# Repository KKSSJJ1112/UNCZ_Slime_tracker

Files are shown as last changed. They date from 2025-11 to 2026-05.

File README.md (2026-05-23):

<h2 align="center">🚧 開発中 / 개발중 / Under Development 🚧</h2>

---

# UNCZ SlimeVR Tracker

[🇯🇵 日本語](#日本語) | [🇰🇷 한국어](#한국어) | [🇺🇸 English](#english)

<p align="center">
  <!-- 実演GIF / 실연 GIF / Demo GIF -->
  Demo
</p>

---

## 日本語

### 1. 概要

UNCZ SlimeVR Tracker は SlimeVR エコシステム互換のカスタム IMU トラッカーボードである。ESP32-C3 を中心に IMU・磁気センサ・バッテリー充電・昇降圧 DC-DC を 1 枚に統合し、USB-C 1 ポートで充電とファームウェア書き込みを兼ねる構成となっている。

- ボードサイズ: **約 50mm × 35mm**
- 電源: 1 セル Li-ion / Li-Po **1100mAh**
- 通信: Wi-Fi (ESP32-C3 内蔵)
- 充電/通信: USB-C 単一ポート
- 4 層 PCB 設計

### 2. 使用 IC 一覧

| 役割 | 型番 | 主な仕様 |
|---|---|---|
| MCU | ESP32-C3-MINI-1-H4X | RISC-V, Wi-Fi/BLE, 内蔵アンテナ |
| 昇降圧 DC-DC | TPS63802DSGR | Iq 11µA, EN ピン制御 |
| 充電 IC | BQ24232HRGTR | パワーパス内蔵, OVP 28V |
| IMU | LSM6DSV16XTR | 6 軸, I²C 0x6B |
| 磁気センサ | QMC6309 | 3 軸, I²C 0x7C (オプション実装) |
| USB データ TVS | USBLC6-2SC6 | D+/D- ESD 保護 |
| バッテリー | 1100mAh 1S Li-ion/Li-Po | 公称 3.7V |

### 3. 出力 CLC フィルタ

TPS63802 の出力リップル抑制のため、共振周波数 **約 1.4MHz** をターゲットとした CLC フィルタを実装している。

**フィルタ構成**
- C1 (前段): **10µF**
- L: **1µH**
- C2 (後段): **10µF**
- 共振周波数: f₀ = 1 / (2π√(LC)) ≈ 1.59MHz (C 並列換算)

**スナバ・ダンピング**
LC 共振による Q 値スパイクを抑えるため、後段に並列スナバを配置。
- ダンピング抵抗: **1Ω 抵抗 × 3 個並列 = 0.33Ω**
- スナバ容量: **22µF × 3 個並列 = 66µF**

この構成によりフィルタの Q 値を適切に下げ、過渡応答時のリンギングを抑制している。

<p align="center">
  <!-- LTspice シミュレーション画像 -->
  LTspice Simulation
</p>

### 4. ファイル構成

| フォルダ | 内容 |
|---|---|
| `pic/` | 測定写真、実演 GIF |
| `EASY_EDA_PRO/` | EasyEDA Pro プロジェクトファイル、ライブラリファイル |
| `JLC_PCB/` | ガーバーファイル、BOM、Pick & Place ファイル |
| `Datasheet/` | 使用部品のデータシート |
| `Firmware/` | SlimeVR オープンソースベースのファームウェア |
| `License/` | ライセンスファイル |

### 5. ファームウェア

本プロジェクトのファームウェアに関するすべての部分は **[SlimeVR オープンソースプロジェクト](https://github.com/SlimeVR/SlimeVR-Tracker-ESP)** に準拠する。

### 6. リビジョン履歴

| Rev | 内容 |
|-----|---|
| REV1 | モジュールベースの拡張ボード設計 |
| REV5 | チップベースの再設計 (現行) |

### 7. ライセンス

- **ハードウェア (PCB, 回路図, 3D ファイル)**: [MIT License](https://github.com/KKSSJJ1112/UNCZ_Slime_tracker/blob/main/License/MIT)
- **ドキュメント**: [CC BY-SA 4.0](https://creativecommons.org/licenses/by-sa/4.0/)

---

## 한국어

### 1. 개요

UNCZ SlimeVR Tracker는 SlimeVR 생태계와 호환되는 커스텀 IMU 트래커 보드입니다. ESP32-C3를 중심으로 IMU, 자력계, 배터리 충전 회로, 벅부스트 DC-DC를 한 장의 PCB에 통합했으며, 단일 USB-C 포트로 충전과 펌웨어 장입을 모두 처리합니다.

- 보드 사이즈: **약 50mm × 35mm**
- 전원: 1셀 Li-ion / Li-Po **1100mAh**
- 통신: Wi-Fi (ESP32-C3 내장)
- 충전/통신: USB-C 단일 포트
- 4레이어 PCB 설계

### 2. 사용 IC 목록

| 역할 | 부품 | 주요 사양 |
|---|---|---|
| MCU | ESP32-C3-MINI-1-H4X | RISC-V, Wi-Fi/BLE, 내장 안테나 |
| 벅부스트 DC-DC | TPS63802DSGR | Iq 11µA, EN 핀 제어 |
| 충전 IC | BQ24232HRGTR | 파워패스 내장, OVP 28V |
| IMU | LSM6DSV16XTR | 6축, I²C 0x6B |
| 자력계 | QMC6309 | 3축, I²C 0x7C (옵션 실장) |
| USB 데이터 TVS | USBLC6-2SC6 | D+/D- ESD 보호 |
| 배터리 | 1100mAh 1S Li-ion/Li-Po | 공칭 3.7V |

### 3. 출력 CLC 필터

TPS63802 출력 리플 억제를 위해 공진 주파수 **약 1.4MHz**를 타겟으로 한 CLC 필터를 구성했습니다.

**필터 구성**
- C1 (전단): **10µF**
- L: **1µH**
- C2 (후단): **10µF**
- 공진 주파수: f₀ = 1 / (2π√(LC)) ≈ 1.59MHz (C 병렬 환산)

**스너버 댐핑**
LC 공진으로 인한 Q값 스파이크를 억제하기 위해 후단에 병렬 스너버를 배치하여 의도적으로 Q값을 조정했습니다.
- 댐핑 저항: **1Ω 저항 3개 병렬 = 0.33Ω**
- 스너버 커패시터: **22µF 3개 병렬 = 66µF**

이 구성으로 필터의 Q값을 적절히 낮춰 과도 응답 시 링잉을 억제합니다.

<p align="center">
  <!-- LTspice 시뮬레이션 이미지 -->
  LTspice Simulation
</p>

### 4. 파일 구성

| 폴더 | 내용 |
|---|---|
| `pic/` | 측정 사진, 실연 GIF |
| `EASY_EDA_PRO/` | EasyEDA Pro 프로젝트 파일, 라이브러리 파일 |
| `JLC_PCB/` | 거버 파일, BOM, Pick & Place 파일 |
| `Datasheet/` | 사용 부품 데이터시트 |
| `Firmware/` | SlimeVR 오픈소스 기반 펌웨어 |
| `License/` | 라이센스 파일 |

### 5. 펌웨어

본 프로젝트의 펌웨어와 관련된 모든 부분은 **[SlimeVR 오픈소스 프로젝트](https://github.com/SlimeVR/SlimeVR-Tracker-ESP)** 를 따릅니다.

### 6. 리비전 히스토리

| Rev | 내용 |
|-----|---|
| REV1 | 모듈 기반의 확장 보드 설계 |
| REV5 | 칩 기반의 재설계 (현행) |

### 7. 라이센스

- **하드웨어 (PCB, 회로도, 3D 파일)**: [MIT License](https://github.com/KKSSJJ1112/UNCZ_Slime_tracker/blob/main/License/MIT)
- **문서**: [CC BY-SA 4.0](https://creativecommons.org/licenses/by-sa/4.0/)

---

## English

### 1. Overview

The UNCZ SlimeVR Tracker is a custom IMU tracker board compatible with the SlimeVR ecosystem. Built around the ESP32-C3, it integrates an IMU, magnetometer, battery charger, and buck-boost DC-DC converter onto a single PCB, with a single USB-C port handling both charging and firmware upload.

- Board size: **~50mm × 35mm**
- Power: 1-cell Li-ion / Li-Po **1100mAh**
- Communication: Wi-Fi (ESP32-C3 built-in)
- Charging/Communication: Single USB-C port
- 4-layer PCB design

### 2. IC List

| Role | Part | Key Specs |
|---|---|---|
| MCU | ESP32-C3-MINI-1-H4X | RISC-V, Wi-Fi/BLE, built-in antenna |
| Buck-Boost DC-DC | TPS63802DSGR | Iq 11µA, EN pin control |
| Charger IC | BQ24232HRGTR | Power path built-in, OVP 28V |
| IMU | LSM6DSV16XTR | 6-axis, I²C 0x6B |
| Magnetometer | QMC6309 | 3-axis, I²C 0x7C (optional) |
| USB Data TVS | USBLC6-2SC6 | D+/D- ESD protection |
| Battery | 1100mAh 1S Li-ion/Li-Po | Nominal 3.7V |

### 3. Output CLC Filter

A CLC filter targeting a resonant frequency of **~1.4MHz** is implemented to suppress output ripple from the TPS63802.

**Filter Configuration**
- C1 (front): **10µF**
- L: **1µH**
- C2 (rear): **10µF**
- Resonant frequency: f₀ = 1 / (2π√(LC)) ≈ 1.59MHz (with parallel C)

**Snubber Damping**
To suppress the Q-factor spike caused by LC resonance, a parallel snubber is placed at the rear stage, intentionally tuning the Q-factor.
- Damping resistor: **1Ω × 3 in parallel = 0.33Ω**
- Snubber capacitor: **22µF × 3 in parallel = 66µF**

This configuration appropriately lowers the filter's Q-factor, suppressing ringing during transient response.

<p align="center">
  <!-- LTspice simulation image -->
  LTspice Simulation
</p>

### 4. File Structure

| Folder | Contents |
|---|---|
| `pic/` | Measurement photos, demo GIFs |
| `EASY_EDA_PRO/` | EasyEDA Pro project files, library files |
| `JLC_PCB/` | Gerber files, BOM, Pick & Place files |
| `Datasheet/` | Datasheets of used components |
| `Firmware/` | SlimeVR open-source-based firmware |
| `License/` | License files |

### 5. Firmware

All firmware-related portions of this project follow the **[SlimeVR open-source project](https://github.com/SlimeVR/SlimeVR-Tracker-ESP)**.

### 6. Revision History

| Rev | Description |
|-----|---|
| REV1 | Module-based expansion board design |
| REV5 | Chip-based redesign (current) |

### 7. License

- **Hardware (PCB, Schematics, 3D files)**: [MIT License](https://github.com/KKSSJJ1112/UNCZ_Slime_tracker/blob/main/License/MIT)
- **Documentation**: [CC BY-SA 4.0](https://creativecommons.org/licenses/by-sa/4.0/)

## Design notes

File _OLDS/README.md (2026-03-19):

asd

# UNCZ_Slime_tracker

[English](#english) | [한국어](#한국어)

---

## English

### Overview
Custom SlimeVR tracker.

### Specifications
| Item | Description |
|---|---|
| MCU | ESP32-C3 Super Mini |
| IMU | SlimeVR Mumo Breakout Module V1 (ICM-45686 + QMC6309) |
| Battery | 1100mAh Li-Po |
| PCB Size | ~80mm x 30mm |

## REV01
<details>
### Features
- **Optimized Power Circuit**: Minimized ripple and noise (77mV → 20mV)
- **Compact Form Factor**: Streamlined 2-layer PCB design
- **Production Ready**: Includes JLCPCB manufacturing files

### Repository Structure
```
├── 3D/                    # 3D model files (STL - case, mount, etc.)
├── Datasheets/            # Component datasheets
├── Demonstration_Video/   # Demo videos
├── SlimeVR/               # SlimeVR firmware source code
├── KiCad/                 # KiCad project files
│   ├── *.kicad_pcb
│   ├── *.kicad_sch
│   └── *.kicad_pro
├── License/               # License files
├── Measurement_Pic/       # Power circuit ripple measurement photos
└── Production/            # Manufacturing files
    ├── BOM.csv            # Bill of Materials (JLCPCB format)
    └── Positions.csv      # Pick and place file
```

### Manufacturing
Production files are optimized for JLCPCB:
1. Generate Gerber and drill files from KiCad project (`KiCad/` folder)
2. Upload generated Gerber files to JLCPCB
3. Use provided BOM and position files for SMT assembly

### Firmware

Based on the official SlimeVR open-source firmware.  
Original repository: https://github.com/SlimeVR/SlimeVR-Tracker-ESP

This repository contains only the modified files. Clone the original repository first, then apply these changes.

#### Modified Files

| File | Changes |
|---|---|
| `src/defines.h` | Hardcoded WiFi credentials, battery monitoring disabled, dual sensor config (`SENSOR_DESC_LIST` - 0x69, 0x68), SDO pin control (`PIN_IMU_SDO = 5`) |
| `src/main.cpp` | SDO pin initialization (GPIO5 → HIGH, 200ms delay), WiFi credentials fallback |
| `src/network/wifihandler.cpp` | Hardcoded WiFi credentials (`tryHardcodedCredentials()` function) |
| `src/network/wifihandler.h` | WiFi timeout reduced: 11s → 4s |
| `src/sensors/softfusion/drivers/icm45base.h` | Default I2C address changed: 0x68 → 0x69 |
| `board-defaults.json` | `BOARD_LOLIN_C3_MINI` dual sensor config (Sensor 0: 0x69, Sensor 1: 0x68) |
| `platformio.ini` | Upload flags adjusted (`--after=no_reset`) |

#### Key Features
- ✅ Dual sensor support (I2C address 0x68 + 0x69)
- ✅ Dynamic SDO pin control (GPIO5 for address separation)
- ✅ Improved WiFi stability (timeout adjustment, multiple fallback)
- ✅ Battery monitoring disabled

#### Dual Sensor Setup
When using 2 sensors, **short the INT pin of the secondary tracker to GND**.

#### Build & Flash
1. Install PlatformIO
2. Open `SlimeVR/` folder in VSCode
3. Build and upload to ESP32-C3

#### WiFi Configuration
Edit the following files and replace WiFi credentials:

1. **src/defines.h** (Line 13, 18)
   - Change `WIFI_CREDS_SSID` to your WiFi SSID
   - Change `WIFI_CREDS_PASSWD` to your WiFi password

2. **src/main.cpp** (Line 104, 105)
   - Change `WIFI_CREDS_SSID` to your WiFi SSID  
   - Change `WIFI_CREDS_PASSWD` to your WiFi password

3. **src/network/wifihandler.cpp** (Line 310, 311)
   - Change `HARDCODED_SSID` to your WiFi SSID
   - Change `HARDCODED_PASSWD` to your WiFi password

**Note:** All three locations must match for reliable WiFi connection.

### Power Circuit Measurement
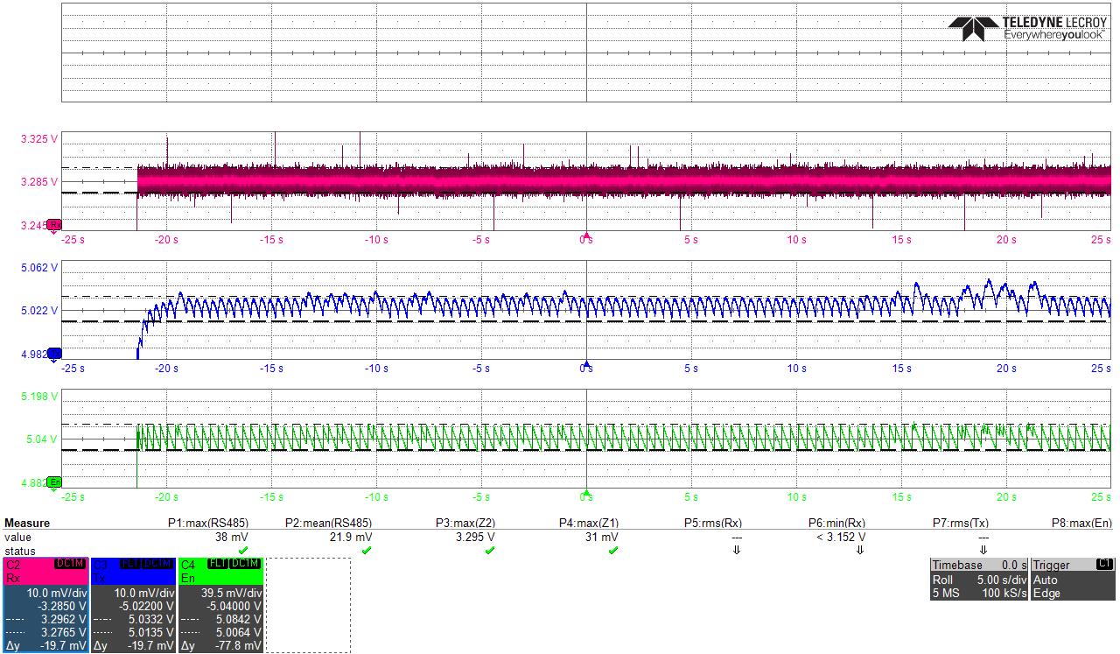
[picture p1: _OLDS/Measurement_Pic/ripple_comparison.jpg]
Power Circuit Comparison


77mV → 20mV  
From bottom to top: immediately after boost converter, after LC filter, and before final IMU power supply.
</details>

### License
- Hardware (PCB, Schematics, 3D files): [MIT License](License/MIT)
- Documentation: [CC BY-SA 4.0](https://creativecommons.org/licenses/by-sa/4.0/)

### Revision History
- **Rev03** (In Progress): Restructured power line routing and added TVS diode for ESD protection, added selectable resistor pads for I2C/SPI configuration, changed power control to EN/CE pin-based switching.
- **Rev02**: Power circuit, Charging circuit changed
- **Rev01**: Initial design

---

## 한국어

### 개요
커스텀 SlimeVR 트래커입니다.

### 사양
| 항목 | 내용 |
|---|---|
| MCU | ESP32-C3 Super Mini |
| IMU | SlimeVR Mumo Breakout Module V1 (ICM-45686 + QMC6309) |
| 배터리 | 1100mAh Li-Po |
| PCB 크기 | 약 80mm x 30mm |

## REV01
<details>
### 특징
- **전원부 최적화**: 리플 및 노이즈 최소화 (77mV → 20mV)
- **컴팩트 설계**: 2레이어 PCB 기반 간결한 설계
- **양산 대응**: JLCPCB 제조 파일 포함

### 저장소 구조
```
├── 3D/                    # 3D 모델 파일 (STL - 케이스, 마운트 등)
├── Datasheets/            # 부품 데이터시트
├── Demonstration_Video/   # 시연 영상
├── SlimeVR/               # SlimeVR 펌웨어 소스 코드
├── KiCad/                 # KiCad 프로젝트 파일
│   ├── *.kicad_pcb
│   ├── *.kicad_sch
│   └── *.kicad_pro
├── License/               # 라이선스 파일
├── Measurement_Pic/       # 전원부 리플 측정 사진
└── Production/            # 제조용 파일
    ├── BOM.csv            # 부품 목록 (JLCPCB 형식)
    └── Positions.csv      # 부품 배치 파일
```

### 제조 방법
JLCPCB 기준 제조 파일 제공:
1. KiCad 프로젝트(`KiCad/` 폴더)에서 Gerber 및 드릴 파일 생성
2. 생성된 Gerber 파일을 JLCPCB에 업로드
3. 제공된 BOM 및 위치 파일로 SMT 조립 주문

### 펌웨어

SlimeVR 공식 오픈소스 펌웨어를 기반으로 합니다.  
원본 저장소: https://github.com/SlimeVR/SlimeVR-Tracker-ESP

이 저장소에는 수정된 파일만 포함되어 있습니다. 원본 저장소를 먼저 클론한 후 변경사항을 적용하세요.

#### 수정된 파일

| 파일 | 변경 내용 |
|---|---|
| `src/defines.h` | WiFi 정보 하드코딩, 배터리 모니터링 비활성화, 듀얼 센서 설정 (`SENSOR_DESC_LIST` - 0x69, 0x68), SDO 핀 제어 (`PIN_IMU_SDO = 5`) |
| `src/main.cpp` | SDO 핀 초기화 (GPIO5 → HIGH, 200ms delay), WiFi credentials fallback |
| `src/network/wifihandler.cpp` | WiFi 정보 하드코딩 (`tryHardcodedCredentials()` 함수) |
| `src/network/wifihandler.h` | WiFi 타임아웃 단축: 11초 → 4초 |
| `src/sensors/softfusion/drivers/icm45base.h` | I2C 기본 주소 변경: 0x68 → 0x69 |
| `board-defaults.json` | `BOARD_LOLIN_C3_MINI` 듀얼 센서 설정 (Sensor 0: 0x69, Sensor 1: 0x68) |
| `platformio.ini` | 업로드 플래그 조정 (`--after=no_reset`) |

#### 핵심 기능
- ✅ 듀얼 센서 지원 (I2C 주소 0x68 + 0x69)
- ✅ SDO 핀 동적 제어 (GPIO5로 센서 주소 분리)
- ✅ WiFi 안정성 개선 (타임아웃 조정, 다중 fallback)
- ✅ 배터리 모니터링 비활성화

#### 듀얼 센서 사용 시
센서 2개 사용 시, **보조 트래커의 INT 핀을 GND에 쇼트**시켜 사용하세요.

#### 빌드 및 업로드
1. PlatformIO 설치
2. VSCode에서 `SlimeVR/` 폴더 열기
3. ESP32-C3에 빌드 및 업로드

#### WiFi 설정
아래 파일들에서 WiFi 정보를 수정하세요:

1. **src/defines.h** (13, 18번째 줄)
   - `WIFI_CREDS_SSID`를 본인의 WiFi SSID로 변경
   - `WIFI_CREDS_PASSWD`를 본인의 WiFi 비밀번호로 변경

2. **src/main.cpp** (104, 105번째 줄)
   - `WIFI_CREDS_SSID`를 본인의 WiFi SSID로 변경
   - `WIFI_CREDS_PASSWD`를 본인의 WiFi 비밀번호로 변경

3. **src/network/wifihandler.cpp** (310, 311번째 줄)
   - `HARDCODED_SSID`를 본인의 WiFi SSID로 변경
   - `HARDCODED_PASSWD`를 본인의 WiFi 비밀번호로 변경

**참고:** 세 곳 모두 동일하게 설정해야 WiFi 연결이 정상 작동합니다.

### 전원부 측정
전원부 비교

77mV → 20mV  
맨 아래부터 승압 직후, LC필터 이후, 최종 IMU 공급 직전
</details>
### 라이선스
- Hardware (PCB, Schematics, 3D files): [MIT License](License/MIT)
- Documentation: [CC BY-SA 4.0](https://creativecommons.org/licenses/by-sa/4.0/)

### 변경 이력
- **Rev03** (현재 진행중) : ESD관련한 배선 구조 변경 및 소자 추가, I2C, SPI 혼용을 위한 선택용 저항 패턴 추가, 전원제어를 EN, CE핀 기반으로 변경
- **Rev02**: 전원부, 충전부 수정
- **Rev01**: 최초 설계

---

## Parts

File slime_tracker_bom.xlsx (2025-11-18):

Reference | Qty | Value | DNP | Exclude from BOM | Exclude from Board | Footprint | JLC PART # | Datasheet
C1 | 1 | 1uF |  |  |  | Capacitor_SMD:C_0805_2012Metric | C1712 | ~
C2,C12,C13 | 3 | 10uF |  |  |  | Capacitor_SMD:C_1206_3216Metric | C70462 | ~
C3 | 1 | 22uF |  |  |  | Capacitor_SMD:C_1206_3216Metric | C5252682 | ~
C4 | 1 | 100nF |  |  |  | Capacitor_SMD:C_1206_3216Metric | C82601 | ~
C5 | 1 | 2.2uF |  |  |  | Capacitor_SMD:C_1206_3216Metric | C577211 | ~
C6 | 1 | 10uF |  |  |  | Capacitor_SMD:C_0805_2012Metric | C6119932 | ~
C7 | 1 | 0.1uF |  |  |  | Capacitor_SMD:C_0805_2012Metric | C519981 | ~
C8 | 1 | 100uF |  |  |  | Capacitor_Tantalum_SMD:CASE-B-3528-21(mm) kemet | C600583 | ~
C9,C10 | 2 | 1.5uF |  |  |  | Capacitor_SMD:C_1206_3216Metric | C282844 | ~
C11 | 1 | 1uF |  |  |  | Capacitor_SMD:C_1206_3216Metric | C107184 | ~
D1 | 1 | red |  |  |  | LED_SMD:LED_1206_3216Metric | C84270 | ~
D2 | 1 | green |  |  |  | LED_SMD:LED_1206_3216Metric | C14641 | ~
D3 | 1 | D |  |  |  | Diode_SMD:D_SOD-323 | C22624
FB1,FB2 | 2 | FerriteBead |  |  |  | Resistor_SMD:R_0805_2012Metric | C67451 | ~
H1,H2 | 2 | MountingHole | DNP | ",MountingHole:MountingHole_3.2mm_M3" | ~ | ~ | ~
H3,H5,H6 | 3 | MountingHole | DNP | MountingHole:ToolingHole_1.152mm | ~ | ~ | ~
J1 | 1 | batt | DNP | ",Connector_JST:JST_PH_S2B-PH-K_1x02_P2.00mm_Horizontal" | ~ | ~ | ~
J3 | 1 | USB_C_Receptacle_PowerOnly_6P |  |  |  | Connector_USB:USB_C_Receptacle_GCT_USB4135-GF-A_6P_TopMnt_Horizontal | C5438410 | https://www.usb.org/sites/default/files/documents/usb_type-c.zip
L1 | 1 | 6.8uH |  |  |  | slime:FXL0420 | C177241 | ~
L2 | 1 | 2.2uH |  |  |  | slime:FXL0420 | C167206 | ~
R1,R5 | 2 | 1.8MOhm |  |  |  | Resistor_SMD:R_0603_1608Metric | C13318 | ~
R2,R3,R6,R7 | 4 | 33Ohm |  |  |  | Resistor_SMD:R_0603_1608Metric | C23140 | ~
R4 | 1 | 390kOhm |  |  |  | Resistor_SMD:R_0603_1608Metric | C23150 | ~
R8 | 1 | 200kOhm |  |  |  | Resistor_SMD:R_0603_1608Metric | C25811 | ~
R9 | 1 | 1MOhm |  |  |  | Resistor_SMD:R_0603_1608Metric | C22935 | ~
R10 | 1 | 4.7kOhm |  |  |  | Resistor_SMD:R_0603_1608Metric | C23162 | ~
R11 | 1 | 3kOhm |  |  |  | Resistor_SMD:R_0603_1608Metric | C4211 | ~
R12 | 1 | 10kOhm |  |  |  | Resistor_SMD:R_0603_1608Metric | C25804 | ~
R13,R14 | 2 | 1kOhm |  |  |  | Resistor_SMD:R_0603_1608Metric | C21190 | ~
R15 | 1 | 0.4Ohm |  |  |  | Resistor_SMD:R_2010_5025Metric | C2999599 | ~
R16,R17 | 2 | 5.1kOhm |  |  |  | Resistor_SMD:R_0603_1608Metric | C23186 | ~
SW1 | 1 | SW_DPDT_x2 | DNP | Button_Switch_THT:SW_Slide_SPDT_Angled_CK_OS102011MA1Q" | ~ | ~ | ~
TP1 | 1 | SCL |  |  |  | TestPoint:TestPoint_Pad_2.5x2.5mm | ~ | ~
TP2 | 1 | SDA |  |  |  | TestPoint:TestPoint_Pad_2.5x2.5mm | ~ | ~
TP3 | 1 | 3.3v |  |  |  | TestPoint:TestPoint_Pad_2.5x2.5mm | ~ | ~
TP4 | 1 | GND |  |  |  | TestPoint:TestPoint_Pad_2.5x2.5mm | ~ | ~
TP5 | 1 | INT2 |  |  |  | TestPoint:TestPoint_Pad_2.5x2.5mm | ~ | ~
U1 | 1 | TP4056 |  |  |  | slime:TP4056_ESOP8 | C725790
U2 | 1 | ~ | DNP | "slime:Slime_IMU_mumo" | ~ | ~ | ~
U3 | 1 | TPS7A0333PDBVR |  |  |  | Package_TO_SOT_SMD:SOT-23-5 | C3749797
U4 | 1 | ESP32 SUPER MINI C3 | DNP | ",slime:esp32" | ~ | ~ | ~
U5 | 1 | TPS61090 |  |  |  | Package_DFN_QFN:QFN-16-1EP_4x4mm_P0.65mm_EP2.7x2.7mm_PullBack_ThermalVias | C206167

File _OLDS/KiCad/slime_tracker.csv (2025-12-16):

Reference | Qty | Value | DNP | Exclude from BOM | Exclude from Board | Footprint | Datasheet
C1 | 1 | 1uF |  |  |  | Capacitor_SMD:C_0805_2012Metric | ~
C2,C12,C13 | 3 | 10uF |  |  |  | Capacitor_SMD:C_1206_3216Metric | ~
C3 | 1 | 22uF |  |  |  | Capacitor_SMD:C_1206_3216Metric | ~
C4 | 1 | 100nF |  |  |  | Capacitor_SMD:C_1206_3216Metric | ~
C5 | 1 | 2.2uF |  |  |  | Capacitor_SMD:C_1206_3216Metric | ~
C6 | 1 | 10uF |  |  |  | Capacitor_SMD:C_0805_2012Metric | ~
C7 | 1 | 0.1uF |  |  |  | Capacitor_SMD:C_0805_2012Metric | ~
C8 | 1 | 100uF |  |  |  | Capacitor_Tantalum_SMD:CP_EIA-3528-21_Kemet-B | ~
C9,C10 | 2 | 1.5uF |  |  |  | Capacitor_SMD:C_1206_3216Metric | ~
C11 | 1 | 1uF |  |  |  | Capacitor_SMD:C_1206_3216Metric | ~
D1 | 1 | red |  |  |  | LED_SMD:LED_1206_3216Metric | ~
D2 | 1 | green |  |  |  | LED_SMD:LED_1206_3216Metric | ~
D3 | 1 | D |  |  |  | Diode_SMD:D_SOD-123 | ~
FB1 | 1 | FerriteBead |  |  |  | Resistor_SMD:R_0805_2012Metric | ~
H1,H2 | 2 | MountingHole |  | BOM에서 제외됨 |  | MountingHole:MountingHole_3.2mm_M3 | ~
J1 | 1 | batt |  | BOM에서 제외됨 |  | Connector_JST:JST_PH_S2B-PH-K_1x02_P2.00mm_Horizontal | ~
J3 | 1 | USB_C_Receptacle_PowerOnly_6P |  |  |  | Connector_USB:USB_C_Receptacle_GCT_USB4135-GF-A_6P_TopMnt_Horizontal | https://www.usb.org/sites/default/files/documents/usb_type-c.zip
L1 | 1 | 6.8uH |  |  |  | slime:FXL0420 | ~
L2 | 1 | 2.2uH |  |  |  | slime:FXL0420 | ~
R1,R5 | 2 | 1.8MΩ |  |  |  | Resistor_SMD:R_0603_1608Metric | ~
R2,R3,R6,R7 | 4 | 33 |  |  |  | Resistor_SMD:R_0603_1608Metric | ~
R4 | 1 | 390kΩ |  |  |  | Resistor_SMD:R_0603_1608Metric | ~
R8 | 1 | 200kΩ |  |  |  | Resistor_SMD:R_0603_1608Metric | ~
R9 | 1 | 1MΩ |  |  |  | Resistor_SMD:R_0603_1608Metric | ~
R10 | 1 | 4.7kΩ |  |  |  | Resistor_SMD:R_0603_1608Metric | ~
R11 | 1 | 3kΩ |  |  |  | Resistor_SMD:R_0603_1608Metric | ~
R12 | 1 | 10kΩ |  |  |  | Resistor_SMD:R_0603_1608Metric | ~
R13,R14 | 2 | 1kΩ |  |  |  | Resistor_SMD:R_0603_1608Metric | ~
R15 | 1 | 0.4Ω |  |  |  | Resistor_SMD:R_2010_5025Metric | ~
R16,R17 | 2 | 5.1kΩ |  |  |  | Resistor_SMD:R_0603_1608Metric | ~
SW1 | 1 | SW_DPDT_x2 |  | BOM에서 제외됨 |  | Button_Switch_THT:SW_Slide_SPDT_Angled_CK_OS102011MA1Q | ~
TP1 | 1 | SCL |  |  |  | TestPoint:TestPoint_Pad_2.5x2.5mm | ~
TP2 | 1 | SDA |  |  |  | TestPoint:TestPoint_Pad_2.5x2.5mm | ~
TP3 | 1 | 3.3v |  |  |  | TestPoint:TestPoint_Pad_2.5x2.5mm | ~
TP4 | 1 | GND |  |  |  | TestPoint:TestPoint_Pad_2.5x2.5mm | ~
TP5 | 1 | INT2 |  |  |  | TestPoint:TestPoint_Pad_2.5x2.5mm | ~
U1 | 1 | TP4056 |  |  |  | slime:TP4056_ESOP8
U2 | 1 | ~ |  | BOM에서 제외됨 |  | slime:Slime_IMU_mumo
U3 | 1 | TPS7A0333PDBVR |  |  |  | Package_TO_SOT_SMD:SOT-23-5
U4 | 1 | ESP32 SUPER MINI C3 |  | BOM에서 제외됨 |  | slime:esp32
U5 | 1 | TPS61090 |  |  |  | Package_DFN_QFN:QFN-16-1EP_4x4mm_P0.65mm_EP2.7x2.7mm_PullBack_ThermalVias

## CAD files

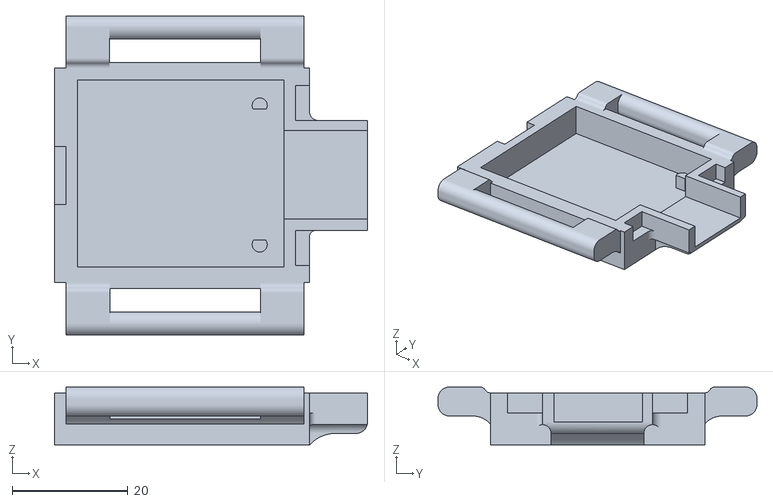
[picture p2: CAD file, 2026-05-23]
_OLDS/3D/sub main.stl
54.0 x 55.0 x 10.0

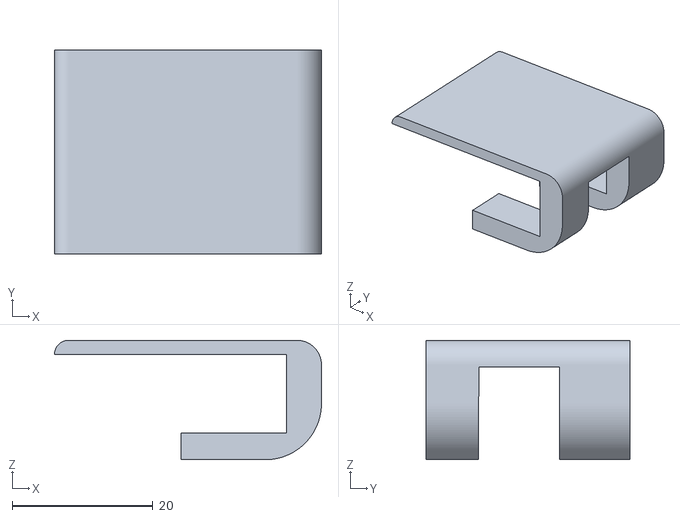
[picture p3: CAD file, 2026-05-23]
_OLDS/3D/chest guide2.stl
38.0 x 29.0 x 17.0

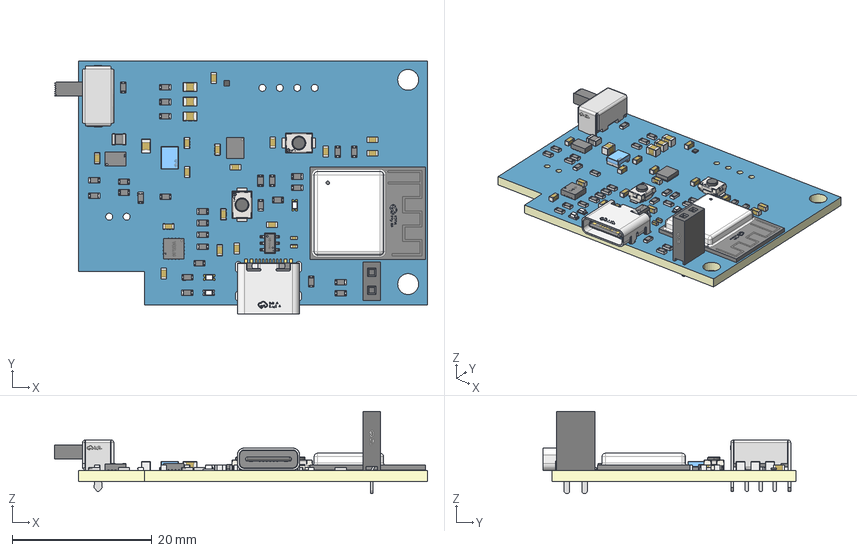
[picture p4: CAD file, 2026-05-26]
EASY_EDA_PRO/3D_PCB1_2026-05-26.step
53.4 x 36.3 x 11.8 mm
Board~Peau
TopCopper~Peau
BottomCopper~Peau
TopFpcStiffener~Peau
BottomFpcStiffener~Peau
LED0603-RD_1~LED0603-RD~Peau x 2
LED0603-R-RD_WHITE~LED0603-R-RD_WHITE~Peau
R0603~R0603~Peau x 28
C0603~C0603_L1.6-W0.8-H0.8~Peau x 16
C0805~C0805_L2.0-W1.3-H1.3~Peau x 4
VQFN-16_L3.0-W3.0-P0.50-TL-EP1.7~VQFN-16_L3.0-W3.0-H1.0-P0.50~Peau
LGA-14_L3.0-W2.5-P0.50-BR~LGA-14_L3.0-W2.5-P0.50-BR~Peau
C0402~C0402_L1.0-W0.5-H0.5~Peau x 2
VSON-10_L3.0-W2.0-P0.50-TL~VSON-10_L3.0-W2.0-P0.50-TL~Peau
SW-TH_SK-12D02-G040~SW-TH_SK-12D02-G040~Peau
IND-SMD_L3.2-W2.5-1~RES-SMD_L3.2-W2.5-H1.3~Peau
USB-C_SMD-TYPE-C-31-M-12_1~USB-C_SMD-TYPE-C-31-M-12_1~Peau
X1-WLB0808-4_L0.8-W0.8-P0.40-TL~X1-WLB0808-4_L0.8-W0.8-P0.40-TL~Peau
SW-SMD_L3.9-W3.0-P4.45~SW-SMD_L3.9-W2.9-H2.0-LS4.8~Peau x 2
IND-SMD_L2.0-W1.6-1~IND-SMD_L2.0-W1.6-1~Peau
SOT-23-6_L2.9-W1.6-P0.95-LS2.8-BL~SOT-23-6_ L2.9-W1.6-H1.5-LS2.8-P0.95~Peau
WIFIM-SMD_ESP32-C3-MINI-1~WIFIM-SMD_ESP32-C3-MINI-1~Peau
HDR-TH_2P-P2.54-V-F~HDR-TH_2P-P2.54-F-LI-1X2P~Peau

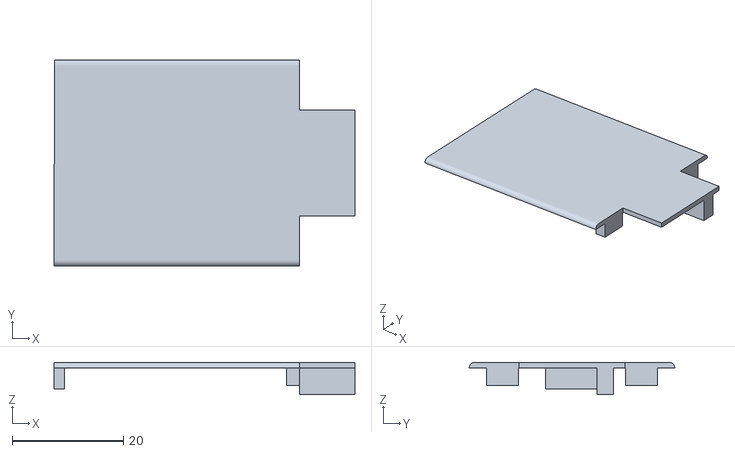
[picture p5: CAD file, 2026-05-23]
_OLDS/3D/sub top.stl
54.1 x 37.0 x 5.80

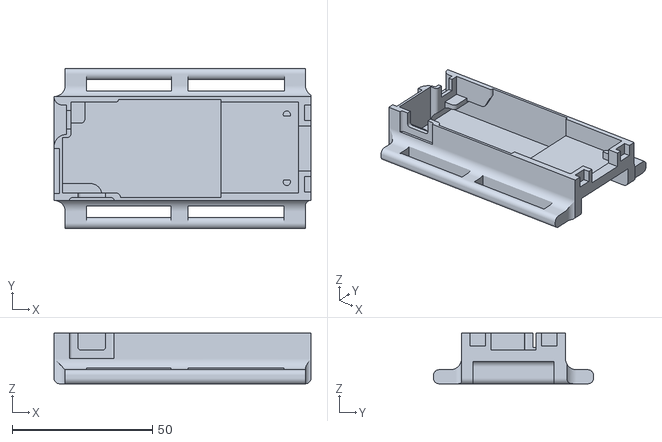
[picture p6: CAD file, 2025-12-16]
_OLDS/3D/base final.stl
91.5 x 57.0 x 18.0

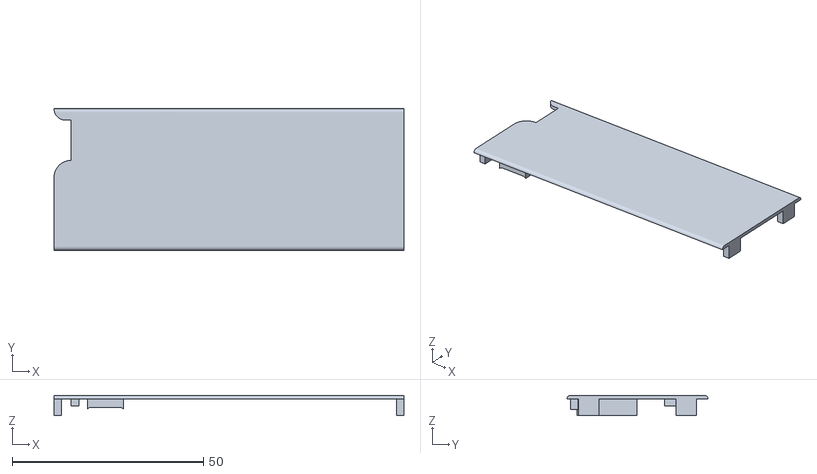
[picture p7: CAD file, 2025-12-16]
_OLDS/3D/top final.stl
91.5 x 37.0 x 5.30

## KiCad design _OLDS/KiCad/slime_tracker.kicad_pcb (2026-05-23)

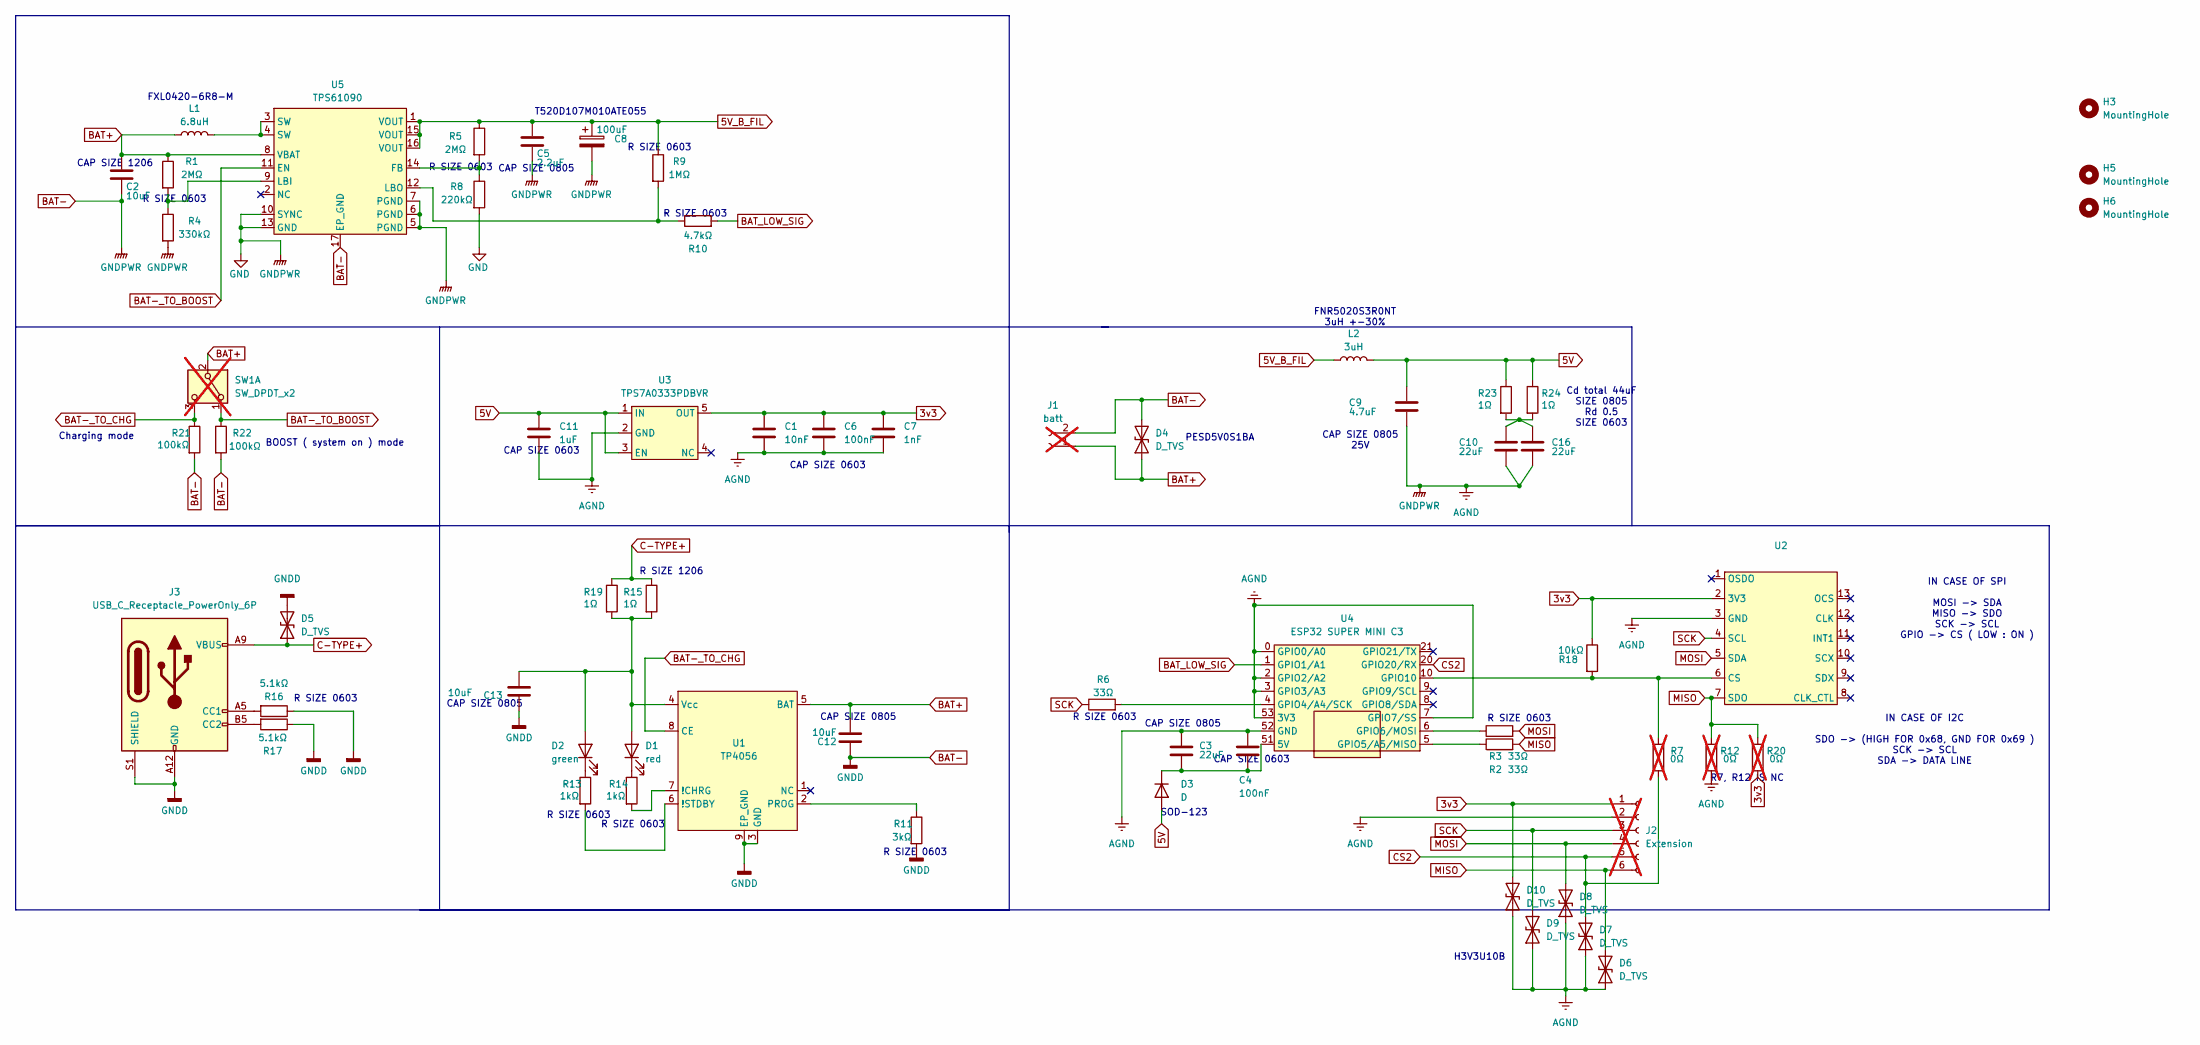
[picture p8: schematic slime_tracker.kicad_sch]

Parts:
C1: 10nF; C_0805_2012Metric
C2: 10uF; C_1206_3216Metric
C3, C10, C16: 22uF; C_0805_2012Metric
C4, C6: 100nF; C_0603_1608Metric
C5: 2.2uF; C_0805_2012Metric
C7: 1nF; C_0603_1608Metric
C8: 100uF; CP_EIA-7343-31_Kemet-D
C9: 4.7uF; C_0805_2012Metric
C11: 1uF; C_0603_1608Metric
C12, C13: 10uF; C_0805_2012Metric
D1: red; LED_0805_2012Metric
D2: green; LED_0805_2012Metric
D3: D; D_SOD-123
D4, D5: D_TVS; D_SOD-323
D6, D7, D8, D9, D10: D_TVS; DFN1006-2
H3, H5, H6: MountingHole; ToolingHole_1.152mm
J1: batt; JST_PH_S2B-PH-K_1x02_P2.00mm_Horizontal; not fitted
J2: Extension; JST_PH_S6B-PH-K_1x06_P2.00mm_Horizontal; not fitted
J3: USB_C_Receptacle_PowerOnly_6P; USB_C_Receptacle_GCT_USB4135-GF-A_6P_TopMnt_Horizontal
L1: 6.8uH; FXL0420
L2: 3uH; FNR5020S3R0NT
R1, R5: 2MΩ; R_0603_1608Metric
R2, R3, R6: 33Ω; R_0603_1608Metric
R4: 330kΩ; R_0603_1608Metric
R7, R12, R20: 0Ω; R_0603_1608Metric; not fitted
R8: 220kΩ; R_0603_1608Metric
R9: 1MΩ; R_0603_1608Metric
R10: 4.7kΩ; R_0603_1608Metric
R11: 3kΩ; R_0603_1608Metric
R13, R14: 1kΩ; R_0603_1608Metric
R15, R19: 1Ω; R_1206_3216Metric
R16, R17: 5.1kΩ; R_0603_1608Metric
R18: 10kΩ; R_0603_1608Metric
R21, R22: 100kΩ; R_0603_1608Metric
R23, R24: 1Ω; R_0603_1608Metric
SW1: SW_DPDT_x2; SW_Slide_SPDT_Angled_CK_OS102011MA1Q; not fitted
U1: TP4056; TP4056_ESOP8
U2: Slime_IMU_mumo
U3: TPS7A0333PDBVR; SOT-23-5
U4: ESP32 SUPER MINI C3; esp32
U5: TPS61090; QFN-16-1EP_4x4mm_P0.65mm_EP2.7x2.7mm_PullBack_ThermalVias

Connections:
3v3: C1.1, C6.1, C7.1, D10.2 (A2), J2.1, R18.1, R20.1, U2.2 (3V3), U3.5 (OUT)
5V: C9.2, C11.1, D3.2 (A), L2.2, R23.1, R24.1, U3.1 (IN), U3.3 (EN)
5V_B_FIL: C5.2, C8.1, L2.1, R5.1, R9.1, U5.1 (VOUT), U5.15 (VOUT), U5.16 (VOUT)
BAT+: C2.2, C12.1, D4.1 (A1), J1.1, L1.1, R1.1, SW1.2 (B), U1.5 (BAT), U5.8 (VBAT)
BAT-: C1.2, C2.1, C3.2, C4.2, C5.1, C6.2, C7.2, C8.2, C9.1, C10.1, C11.2, C12.2, C13.2, C16.1, D4.2 (A2), D5.2 (A2), D6.1 (A1), D7.1 (A1), D8.1 (A1), D9.1 (A1), D10.1 (A1), J1.2, J2.2, J3.A12 (GND), J3.B12 (GND), J3.S1 (SHIELD), R4.2, R8.2, R11.2, R12.1, R16.1, R17.1, R21.2, R22.2, U1.3 (GND), U1.9 (EP_GND), U2.3 (GND), U3.2 (GND), U4.0 (GPIO0/A0), U4.2 (GPIO2/A2), U4.3 (GPIO3/A3), U4.7 (GPIO7/SS), U4.52 (GND), U4.53 (3V3), U5.5 (PGND), U5.6 (PGND), U5.7 (PGND), U5.10 (SYNC), U5.13 (GND), U5.17 (EP_GND)
BAT-_TO_BOOST: R22.1, SW1.1 (A), U5.11 (EN)
BAT-_TO_CHG: R21.1, SW1.3 (C), U1.8 (CE)
BAT_LOW_SIG: R10.2, U4.1 (GPIO1/A1)
C-TYPE+: D5.1 (A1), J3.A9 (VBUS), J3.B9 (VBUS), R15.1, R19.1
CS2: D7.2 (A2), J2.5, R7.1, U4.20 (GPIO20/RX)
MISO: D6.2 (A2), J2.6, R2.2, R12.2, R20.2, U2.7 (SDO)
MOSI: D8.2 (A2), J2.4, R3.2, U2.5 (SDA)
unnamed: C10.2, C16.2, R23.2, R24.2
unnamed: C13.1, D1.2 (A), D2.2 (A), R15.2, R19.2, U1.4 (Vcc)
unnamed: D1.1 (K), R14.1
unnamed: D2.1 (K), R13.1
unnamed: C3.1, C4.1, D3.1 (K), U4.51 (5V)
unnamed: J3.A5 (CC1), R16.2
unnamed: J3.B5 (CC2), R17.2
unnamed: L1.2, U5.3 (SW), U5.4 (SW)
unnamed: R14.2, U1.7 (!CHRG)
unnamed: R13.2, U1.6 (!STDBY)
unnamed: R11.1, U1.2 (PROG)
unnamed: R7.2, R18.2, U2.6 (CS), U4.10 (GPIO10)
unnamed: R6.2, U4.4 (GPIO4/A4/SCK)
unnamed: R2.1, U4.5 (GPIO5/A5/MISO)
unnamed: R3.1, U4.6 (GPIO6/MOSI)
unnamed: R5.2, R8.1, U5.14 (FB)
unnamed: R1.2, R4.1, U5.9 (LBI)
unnamed: R9.2, R10.1, U5.12 (LBO)
SCK: D9.2 (A2), J2.3, R6.1, U2.4 (SCL)

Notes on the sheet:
H3V3U10B
CAP SIZE 0603
R SIZE 0603
CAP SIZE 0603
R SIZE 1206
BOOST ( system on ) mode
CAP SIZE 0805
Cd total 44uF SIZE 0805 Rd 0.5 SIZE 0603
FNR5020S3R0NT 3uH +-30%
CAP SIZE 0805 25V
IN CASE OF I2C SDO -> (HIGH FOR 0x68, GND FOR 0x69 ) SCK -> SCL SDA -> DATA LINE
T520D107M010ATE055
FXL0420-6R8-M
SOD-123
Charging mode
PESD5V0S1BA
CAP SIZE 1206
R7, R12 IS NC
IN CASE OF SPI MOSI -> SDA MISO -> SDO SCK -> SCL GPIO -> CS ( LOW : ON )

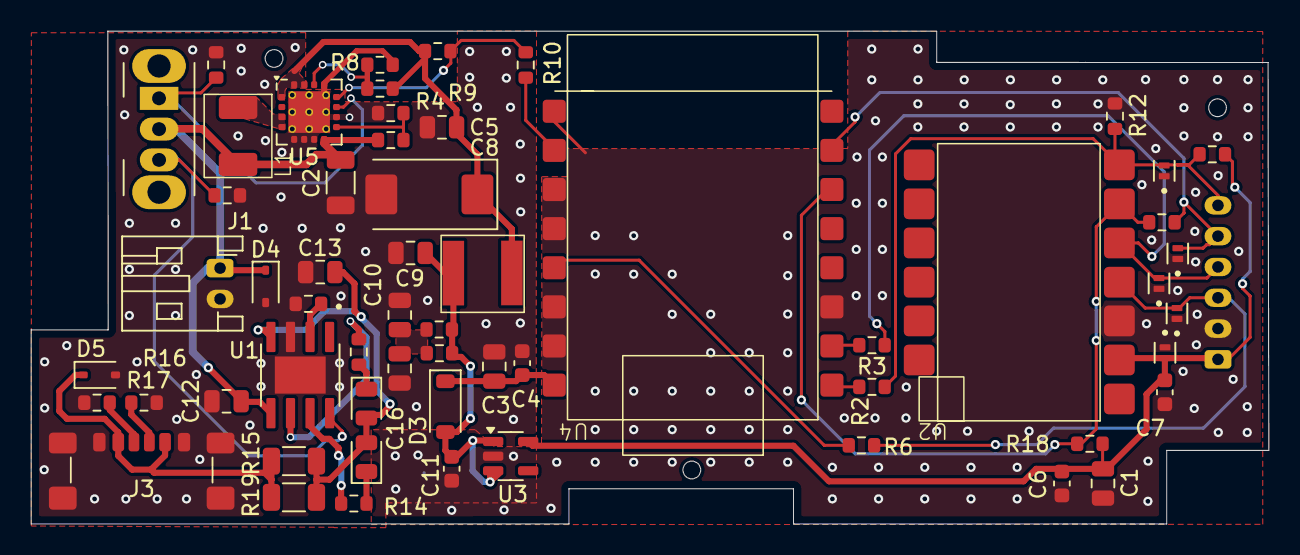
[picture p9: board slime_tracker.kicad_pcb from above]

Board: 2 copper layers, 80.4 x 32.0 mm, 62 parts (0 on the bottom side), 31 nets.

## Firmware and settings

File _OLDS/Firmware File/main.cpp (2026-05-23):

/*
    SlimeVR Code is placed under the MIT license
    Copyright (c) 2021 Eiren Rain & SlimeVR contributors
*/

#include <i2cscan.h>
#include "GlobalVars.h"
#include "Wire.h"
#include "batterymonitor.h"
#include "credentials.h"
#include "debugging/TimeTaken.h"
#include "globals.h"
#include "logging/Logger.h"
#include "ota.h"
#include "serial/serialcommands.h"
#include "status/TPSCounter.h"

Timer<> globalTimer;
SlimeVR::Logging::Logger logger("SlimeVR");
SlimeVR::Sensors::SensorManager sensorManager;
SlimeVR::LEDManager ledManager;
SlimeVR::Status::StatusManager statusManager;
SlimeVR::Configuration::Configuration configuration;
SlimeVR::Network::Manager networkManager;
SlimeVR::Network::Connection networkConnection;
SlimeVR::WiFiNetwork wifiNetwork;
SlimeVR::WifiProvisioning wifiProvisioning;

#if DEBUG_MEASURE_SENSOR_TIME_TAKEN
SlimeVR::Debugging::TimeTakenMeasurer sensorMeasurer{"Sensors"};
#endif

int sensorToCalibrate = -1;
bool blinking = false;
unsigned long blinkStart = 0;
unsigned long loopTime = 0;
unsigned long lastStatePrint = 0;
bool secondImuActive = false;
BatteryMonitor battery;
TPSCounter tpsCounter;

void setup() {
    // 시리얼 통신 시작 (USB CDC On Boot 설정이 중요)
    Serial.begin(serialBaudRate);
    globalTimer = timer_create_default();

    Serial.println();
    Serial.println();
    Serial.println();

    logger.info("SlimeVR v" FIRMWARE_VERSION " starting up...");

    char vendorBuffer[512];
    size_t writtenLength;

    if (strlen(VENDOR_URL) == 0) {
        sprintf(vendorBuffer, "Vendor: %s, product: %s%n", VENDOR_NAME, PRODUCT_NAME, &writtenLength);
    } else {
        sprintf(vendorBuffer, "Vendor: %s (%s), product: %s%n", VENDOR_NAME, VENDOR_URL, PRODUCT_NAME, &writtenLength);
    }

    if (strlen(UPDATE_ADDRESS) > 0 && strlen(UPDATE_NAME) > 0) {
        sprintf(vendorBuffer + writtenLength, ", firmware update url: %s, name: %s", UPDATE_ADDRESS, UPDATE_NAME);
    }
    logger.info("%s", vendorBuffer);

    statusManager.setStatus(SlimeVR::Status::LOADING, true);

    // [최우선] SDO 핀을 먼저 설정 (센서 주소 충돌 방지)
#ifdef PIN_IMU_SDO
    pinMode(PIN_IMU_SDO, OUTPUT);
    digitalWrite(PIN_IMU_SDO, HIGH);
    delay(200); // 충분한 안정화 시간 (USB 미연결 시에도 안정적)
    logger.info("GPIO%d (SDO) set to HIGH for dual sensor setup", PIN_IMU_SDO);
#endif

    ledManager.setup();
    configuration.setup();

    SerialCommands::setUp();

    auto clearResult = I2CSCAN::clearBus(PIN_IMU_SDA, PIN_IMU_SCL);
    if (clearResult != 0) {
        logger.warn("Can't clear I2C bus, error %d", clearResult);
    }

#ifdef ESP32
    Wire.end();
#endif
    Wire.begin(static_cast<int>(PIN_IMU_SDA), static_cast<int>(PIN_IMU_SCL));
#ifdef ESP32
    Wire.setTimeOut(150);
#endif
    Wire.setClock(I2C_SPEED);

    // IMU 부팅을 위한 대기
    delay(500);

    // [핵심] sensorManager.setup() 내부에서 SPI 초기화가 진행됩니다.
    sensorManager.setup();

    // WiFi credentials 강제 설정 (빌드 캐시 문제 우회)
    #ifndef WIFI_CREDS_SSID
    #define WIFI_CREDS_SSID "your-ssid"
    #define WIFI_CREDS_PASSWD "your-password"
    #endif
    logger.info("WiFi credentials: SSID='%s', Pass length=%d", WIFI_CREDS_SSID, strlen(WIFI_CREDS_PASSWD));

    networkManager.setup();
    OTA::otaSetup(otaPassword);
    battery.Setup();

    statusManager.setStatus(SlimeVR::Status::LOADING, false);

    sensorManager.postSetup();

    loopTime = micros();
    tpsCounter.reset();
}

void loop() {
    tpsCounter.update();
    globalTimer.tick();
    SerialCommands::update();
    OTA::otaUpdate();
    networkManager.update();

#if DEBUG_MEASURE_SENSOR_TIME_TAKEN
    sensorMeasurer.before();
#endif
    sensorManager.update();
#if DEBUG_MEASURE_SENSOR_TIME_TAKEN
    sensorMeasurer.after();
#endif

    battery.Loop();
    ledManager.update();
    
    // [수정] I2C 스캔 업데이트 비활성화
    // I2CSCAN::update();

#ifdef TARGET_LOOPTIME_MICROS
    long elapsed = (micros() - loopTime);
    if (elapsed < TARGET_LOOPTIME_MICROS) {
        long sleepus = TARGET_LOOPTIME_MICROS - elapsed - 100;
        long sleepms = sleepus / 1000;
        if (sleepms > 0) {
            delay(sleepms);
            sleepus -= sleepms * 1000;
        }
        if (sleepus > 100) {
            delayMicroseconds(sleepus);
        }
    }
    loopTime = micros();
#endif

#if defined(PRINT_STATE_EVERY_MS) && PRINT_STATE_EVERY_MS > 0
    unsigned long now = millis();
    if (lastStatePrint + PRINT_STATE_EVERY_MS < now) {
        lastStatePrint = now;
        SerialCommands::printState();
    }
#endif
}

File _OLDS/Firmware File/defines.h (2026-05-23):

// defines.h - 최소 필수 정의만 포함 (I2C 모드)

// 배터리 모니터링 비활성화
#ifdef BATTERY_MONITOR
#undef BATTERY_MONITOR
#endif
// BATTERY_MONITOR를 정의하지 않음 = 비활성화

// WiFi 설정 - 강제 하드코딩
#ifdef WIFI_CREDS_SSID
#undef WIFI_CREDS_SSID
#endif
#define WIFI_CREDS_SSID "----"

#ifdef WIFI_CREDS_PASSWD
#undef WIFI_CREDS_PASSWD
#endif
#define WIFI_CREDS_PASSWD "----"

#ifndef IMU
#define IMU IMU_ICM45686
#endif

#ifndef IMU_ROTATION
#define IMU_ROTATION DEG_270
#endif

#ifndef SECOND_IMU_ROTATION
#define SECOND_IMU_ROTATION DEG_270
#endif

#ifndef PRIMARY_IMU_OPTIONAL
#define PRIMARY_IMU_OPTIONAL false
#endif

#ifndef SECONDARY_IMU_OPTIONAL
#define SECONDARY_IMU_OPTIONAL true
#endif

// 센서 설정 리스트 (2개 센서: 0x69 메인, 0x68 서브)
#ifndef SENSOR_DESC_LIST
#define SENSOR_DESC_LIST \
    SENSOR_DESC_ENTRY(IMU_ICM45686, 105, DEG_270, DIRECT_WIRE(4, 6), false, DIRECT_PIN(7), 0) \
    SENSOR_DESC_ENTRY(IMU_ICM45686, 104, DEG_270, DIRECT_WIRE(4, 6), true, DIRECT_PIN(255), 0)
#endif

// SDO 핀 제어 (Sensor 1을 0x69로 설정)
#ifndef PIN_IMU_SDO
#define PIN_IMU_SDO 5
#endif

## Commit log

2025-11-12 Add files via upload
    schematics for Slime tracker.
2025-11-13 아트워크 진행중
2025-11-17 ground plane
2025-11-18 bom. jlc pcb part confirmed
    [slime_tracker_bom.xlsx]
2025-11-19 parts changed
    [Parts Inventory on JLCPCB.xlsx]
2025-12-16 Rename top final.stl to 3D/top final.stl
    [top final.stl]
2025-12-16 kicad project
    [slime_tracker.csv, slime_tracker.kicad_pcb, slime_tracker.kicad_sch]
2025-12-16 for JLC
    [POS.xlsx]
2026-03-05 REV0.3
    REV 0.3
    TVS, EN/CE Based control, SPI I2C selectable Footprint, ESP32 Footprint changed, etc
    [slime_tracker.kicad_pcb, slime_tracker.kicad_sch]
2026-03-05 REV 0.3
    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
2026-03-06 REV3 TD
    TeadDrop
    [slime_tracker.kicad_pcb, slime_tracker.kicad_sch]
2026-03-09 REV_03
    LC filter damp R added
    USB Vbus TVS added
    [slime_tracker.kicad_sch]
2026-03-10 Rev 03 more TVS
    more TVS at extend port line
    [slime_tracker.kicad_pcb, slime_tracker.kicad_sch]
2026-03-11 REV03 3/11
    few PCB layout changed
    [slime_tracker.kicad_pcb, slime_tracker.kicad_sch]
2026-03-12 rev03 agnd pgnd
    agnd pgnd
    [slime_tracker.kicad_pcb, slime_tracker.kicad_sch]
2026-03-19 LPF Changed
    dd
    [slime_tracker.kicad_pcb, slime_tracker.kicad_sch]
2026-03-19 배치 안함
    추가
    [slime_tracker.kicad_sch]
2026-03-19 REV03 BOM
    [bomn.xlsx]
2026-03-20 bom com
    bom com
    [bomn.xlsx]
2026-03-20 rev03 almost
    com
    [slime_tracker.kicad_pcb, slime_tracker.kicad_sch]
2026-03-20 layout edge cut
    [slime_tracker.kicad_pcb]
2026-03-20 pos file
    [pos.xlsx, slime_tracker-bottom-pos.csv, slime_tracker-top-pos.csv]
2026-03-20 board cut
    cc
    [slime_tracker.kicad_pcb]
